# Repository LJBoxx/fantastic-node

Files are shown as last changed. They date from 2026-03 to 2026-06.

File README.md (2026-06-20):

# fantastic-node
A meshtastic node designed to be self sufficient (solar powered) and small/unnoticeable enough to be planted in urban spaces.

I think that mestastic is a great project aiming at making an offgrid network of devices allowing for communication but as part of how it operates, it is limited by the cost and ease of implementing these community ran nodes transmitting packets across a city for instance. 

In this repo, you will find a pcb meant to be affordable, with a 3d printable case and easily sourcable parts.

## Schematic and PCB!

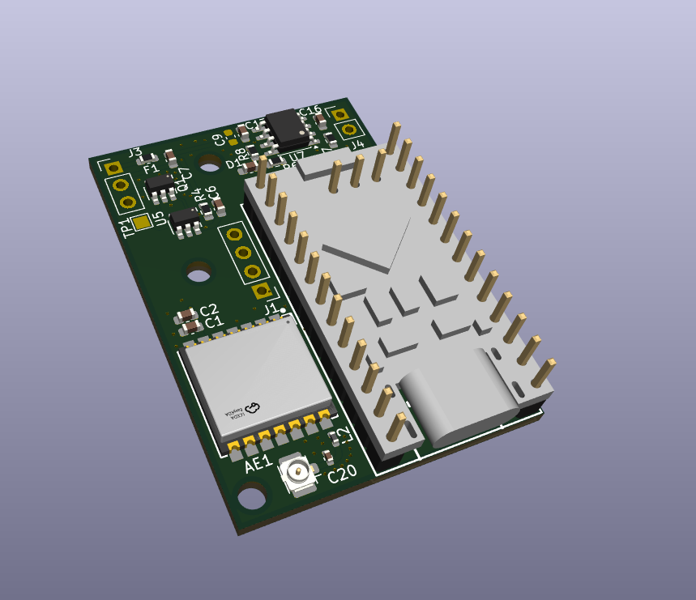
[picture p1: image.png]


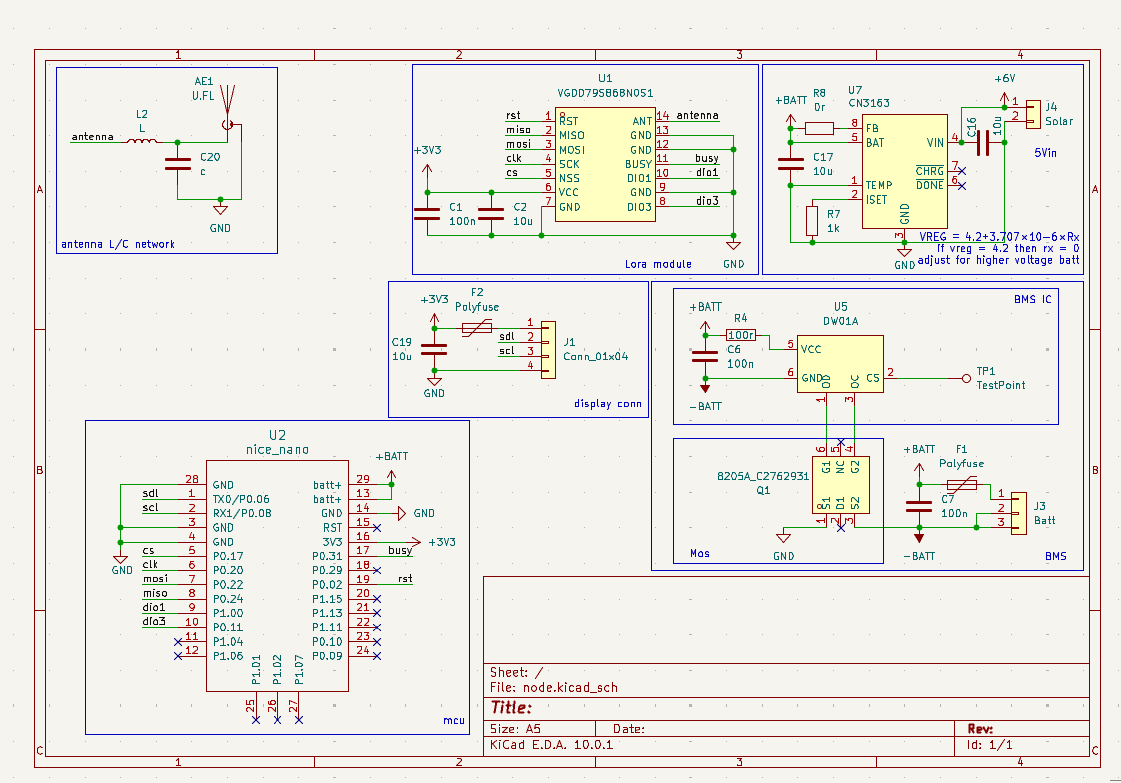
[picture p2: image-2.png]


## Full CAD assembly

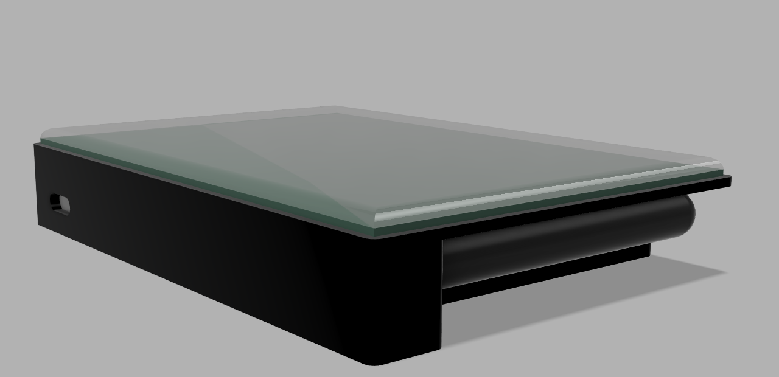
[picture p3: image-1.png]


# BOM 
| Name | Qty | Price  | Link | Note |
| --- | --- | --- | --- | ----- |
| Components | 1 | 20usd  | /hardware/bom_export_mesh.xls |
| PCB | 1x5pcs  | 5usd | https://jlcpcb.com/ | |
|3d printed parts | 2 | 0.1usd | N/A |  Print it yourself|
| total | | usd |  |shipping included

# Assembly

1. Assemble the pcb put all components together and soldere them using the schematic 
2. Print the case+parts and glue the solar pannel in place then place all heat inserts in holes
3. Build the firmware following [meshtastic instructions](https://meshtastic.org/docs/development/firmware/build/) using files in /firmware/* and flash with usb !
4. Put the board and wire antenna plug connect battery to terminals to test out if working and then glue the battery and screw everything together. Use the f3d file to help with assembly :3
(will add more details and pics once i make it)

# ZINEE 
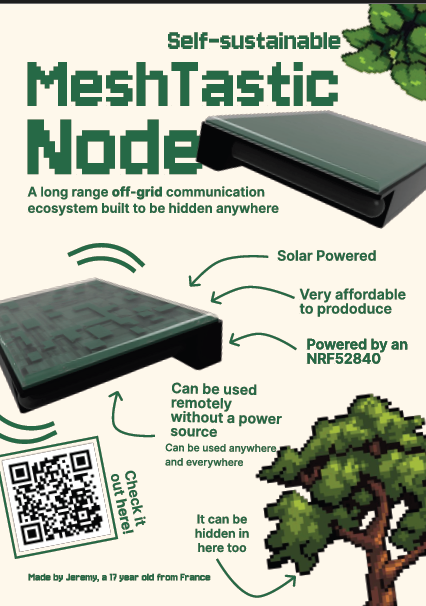
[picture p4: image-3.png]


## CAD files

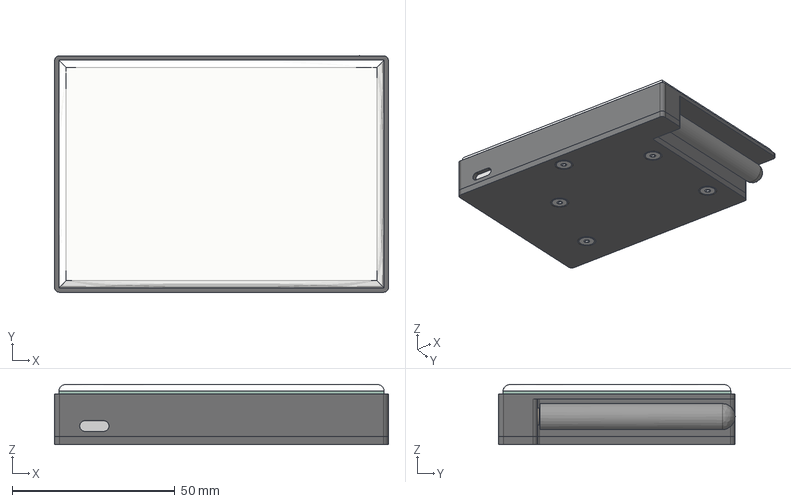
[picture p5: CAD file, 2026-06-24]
hardware/3d/assembly.step
102.7 x 72.7 x 18.5 mm
SOT-23-6 x 2
C_0603_1608Metric x 8
L_0402_1005Metric
SOIC-8_3.9x4.9mm_P1.27mm
R_0603_1608Metric x 4
promicronrf52840
PinHeader_1x13_P2.54mm_Vertical x 2
PinHeader_1x03_P2.54mm_Vertical
WIRELM-SMD_L11.5-W11.5-P1.50-BL
WIRELM-SMD_L11.5-W11.5-P1.50-BL_1
U.FL_Hirose_U.FL-R-SMT-1_Vertical
C_0402_1005Metric
Fuse_0603_1608Metric
node_silkscreen
node_silkscreen_1
node_soldermask
node_soldermask_1
node_PCB
solar module
case
RP-SMA FEMALE TO 90DEG MALE
antenna
battery
SOT-23-6_1 x 2
C_0603_1608Metric_1 x 8
L_0402_1005Metric_1
SOIC-8_3.9x4.9mm_P1.27mm_1
R_0603_1608Metric_1 x 4
promicronrf52840_1
PinHeader_1x13_P2.54mm_Vertical_1 x 2
PinHeader_1x03_P2.54mm_Vertical_1
WIRELM-SMD_L11.5-W11.5-P1.50-BL_2
WIRELM-SMD_L11.5-W11.5-P1.50-BL_3
U.FL_Hirose_U.FL-R-SMT-1_Vertical_1
C_0402_1005Metric_1
Fuse_0603_1608Metric_1
node_silkscreen_2
node_silkscreen_3
node_soldermask_2
node_soldermask_3
node_PCB_1
Insert_M3 x 5
rod
cover
91263A821_Zinc-Plated Alloy Steel Hex Drive Flat Head Screw_1 x 4
91263A863_Zinc-Plated Alloy Steel Hex Drive Flat Head Screw

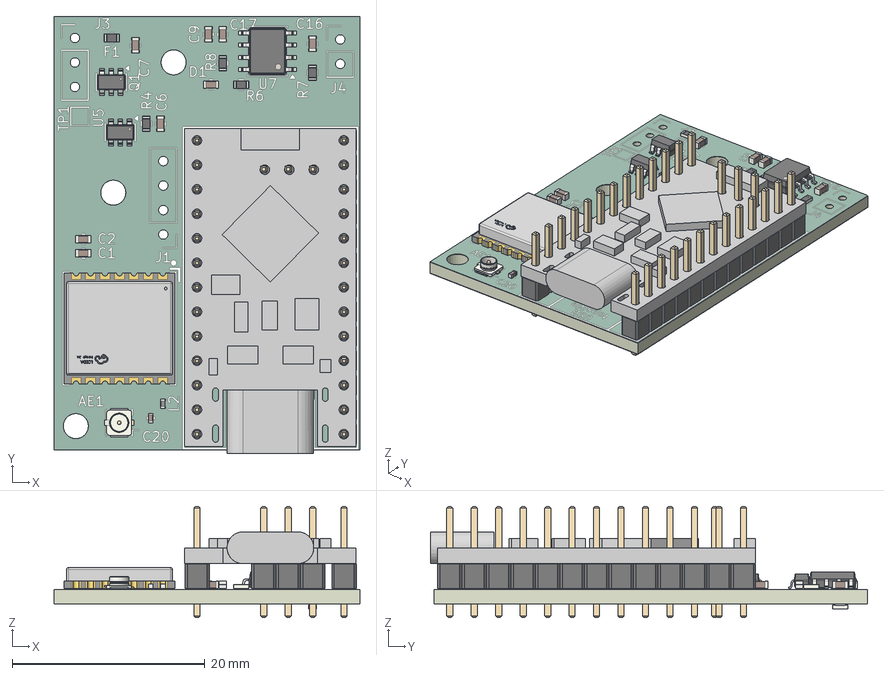
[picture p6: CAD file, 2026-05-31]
hardware/kicad/mesh_node_pcb.step
31.7 x 45.3 x 11.5 mm
SOT-23-6 x 2
C_0603_1608Metric x 8
L_0402_1005Metric
SOIC-8_3.9x4.9mm_P1.27mm
R_0603_1608Metric x 5
promicronrf52840
PinHeader_1x13_P2.54mm_Vertical x 2
PinHeader_1x03_P2.54mm_Vertical
WIRELM-SMD_L11.5-W11.5-P1.50-BL x 2
U.FL_Hirose_U.FL-R-SMT-1_Vertical
C_0402_1005Metric
Fuse_0603_1608Metric
node_silkscreen x 2
node_soldermask x 2
node_PCB

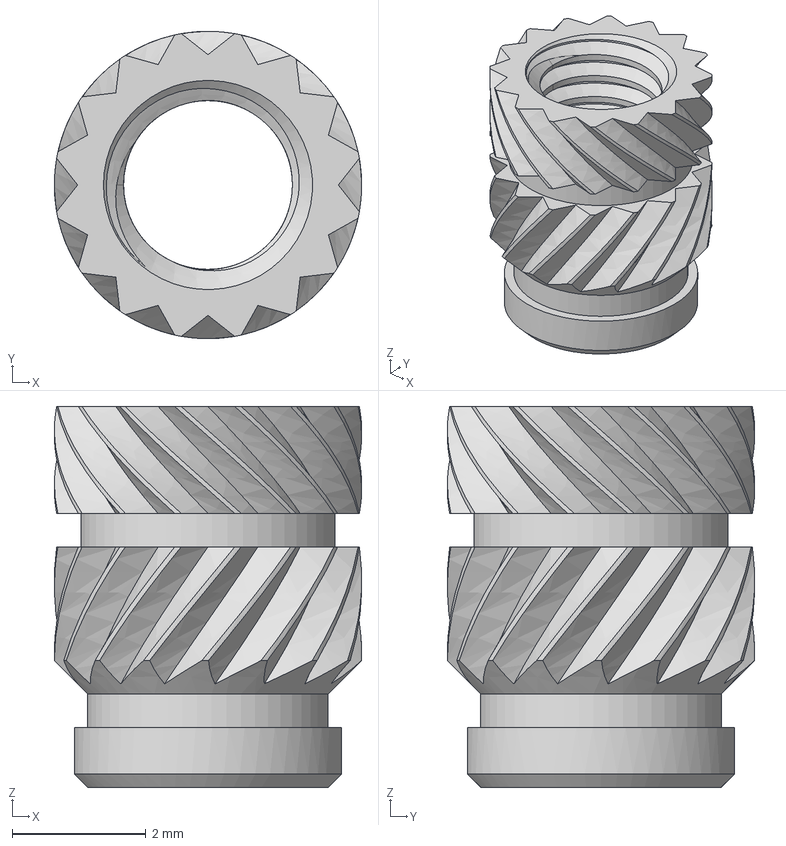
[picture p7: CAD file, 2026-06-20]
hardware/3d/M3_Standard.step
4.60 x 4.60 x 5.70 mm

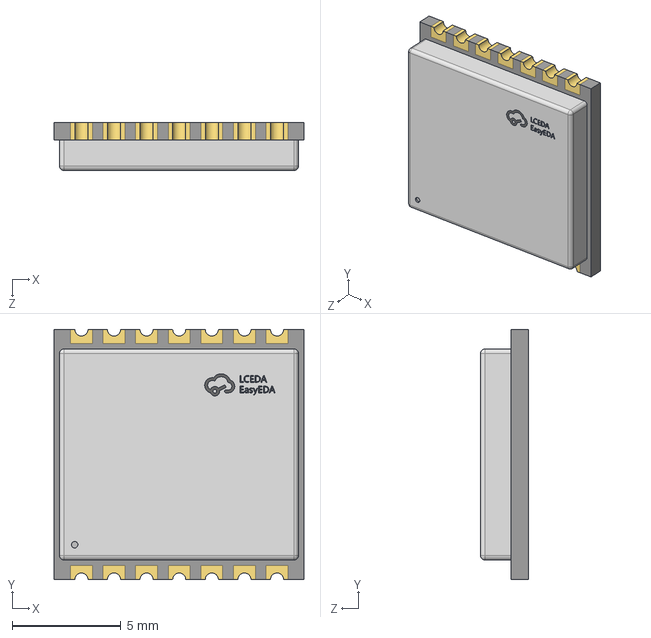
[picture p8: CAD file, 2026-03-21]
hardware/kicad/3d/WIRELM-SMD_L11.5-W11.5-P1.50-BL.step
11.5 x 11.5 x 2.20 mm

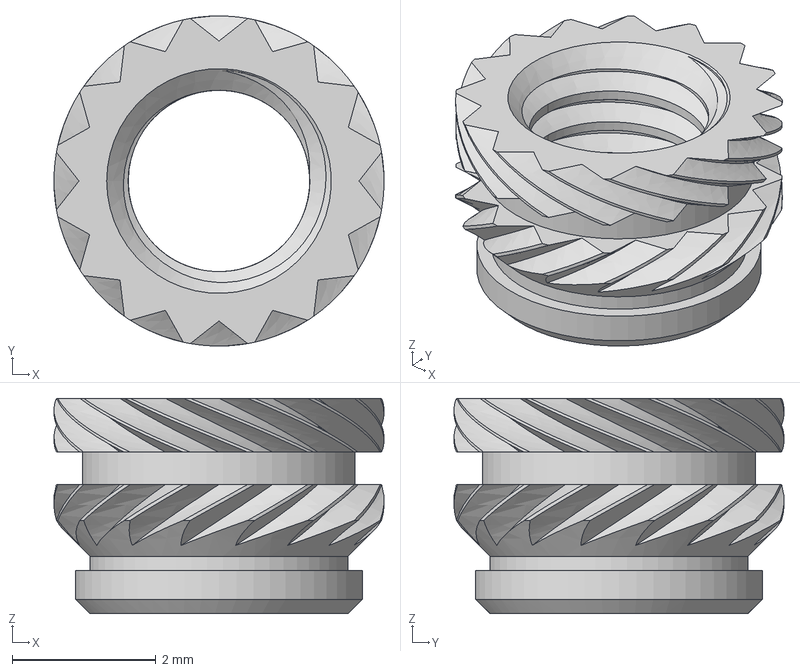
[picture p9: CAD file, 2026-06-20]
hardware/3d/M3_Short.step
4.60 x 4.60 x 3.00 mm

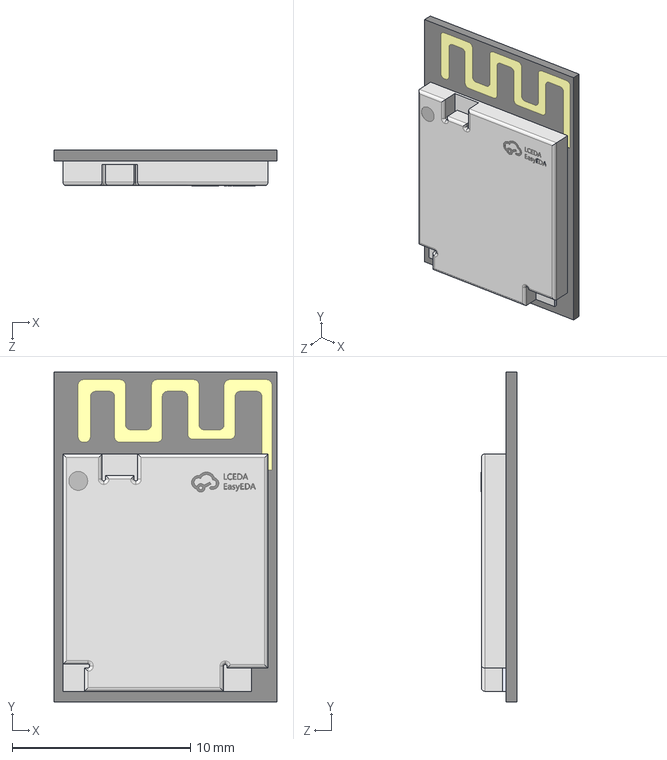
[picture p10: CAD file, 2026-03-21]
hardware/kicad/3d/BULETM-SMD_MS88SF3_V1.0.step
12.5 x 18.5 x 2.01 mm

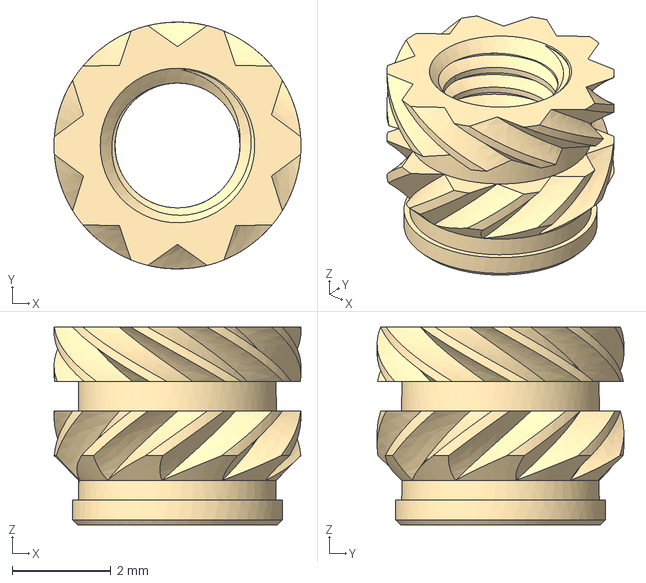
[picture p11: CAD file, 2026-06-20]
hardware/3d/M3_VORON.step
5.00 x 5.00 x 4.00 mm

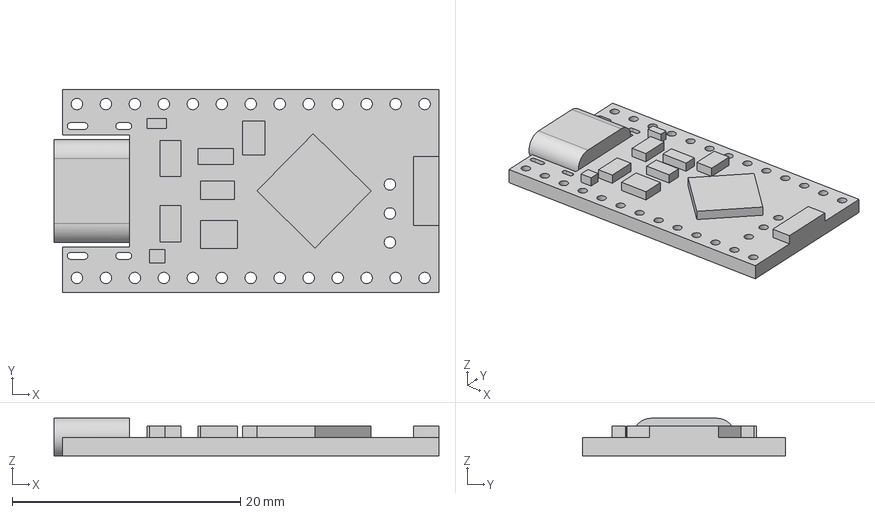
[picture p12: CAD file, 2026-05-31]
hardware/kicad/3d/nrf52840.step
33.7 x 17.8 x 3.30 mm

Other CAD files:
hardware/3d/node-v14.f3z

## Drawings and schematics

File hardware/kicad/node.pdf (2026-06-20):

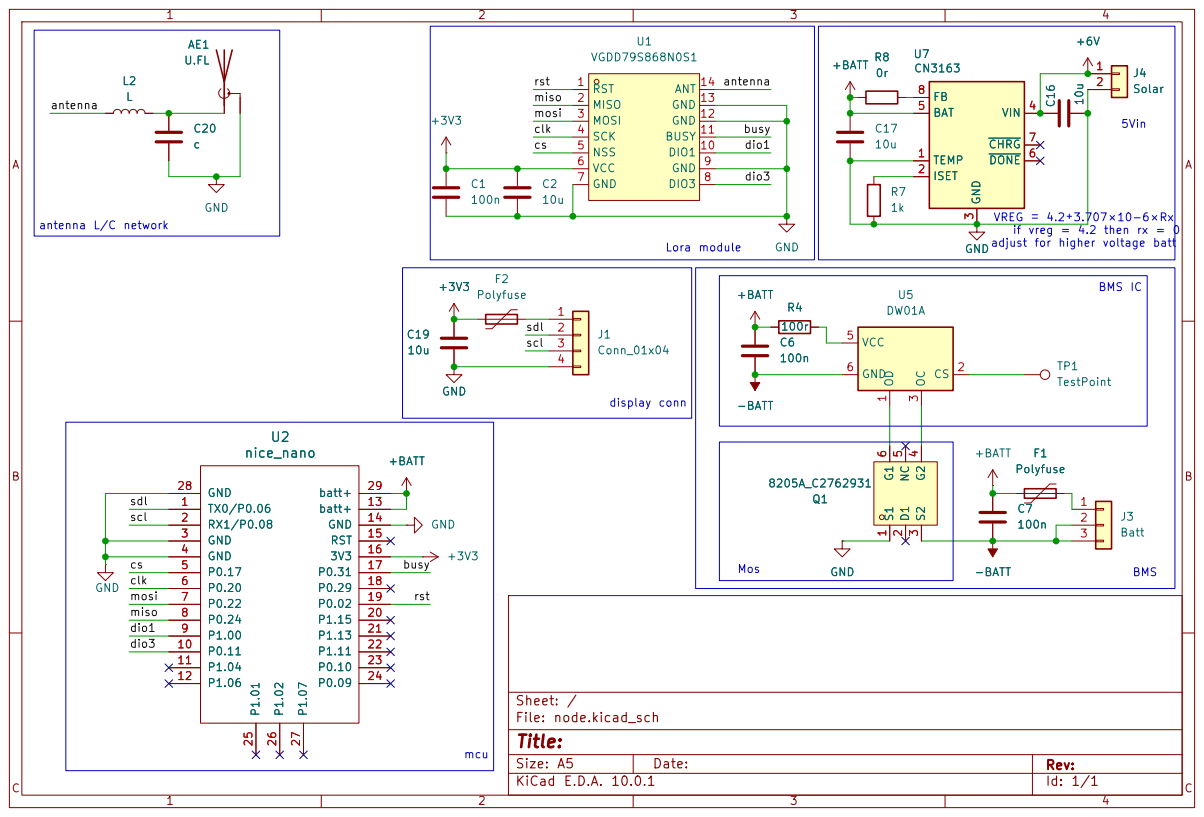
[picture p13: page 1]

if vreg = 4.2 then rx = 0
adjust for higher voltage batt BMS IC

Size: A5 | Rev: | C Date:
KiCad E.D.A. 10.0.1 | Id: 1/1

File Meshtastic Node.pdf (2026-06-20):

# MeshTastic

# Node

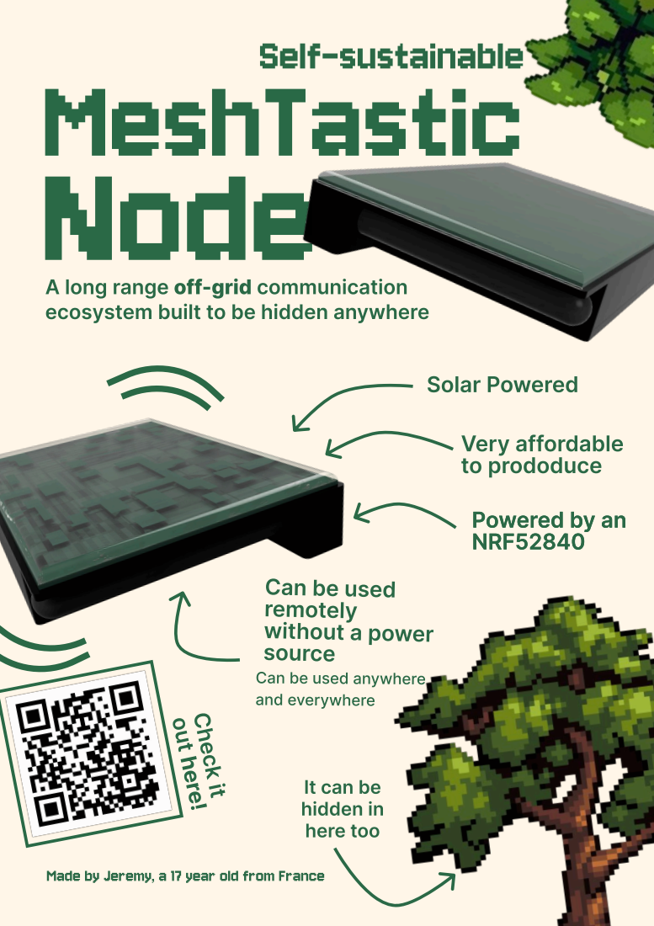
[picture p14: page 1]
Self-sustainable; Solar Powered; out here!; Check it; remotely without a power source

A long range off-grid communication
ecosystem built to be hidden anywhere

Very affordable to prododuce

Powered by an
NRF52840

Can be used

Can be used anywhere
and everywhere

It can be
hidden in
here too

Made by Jeremy, a 17 year old from France

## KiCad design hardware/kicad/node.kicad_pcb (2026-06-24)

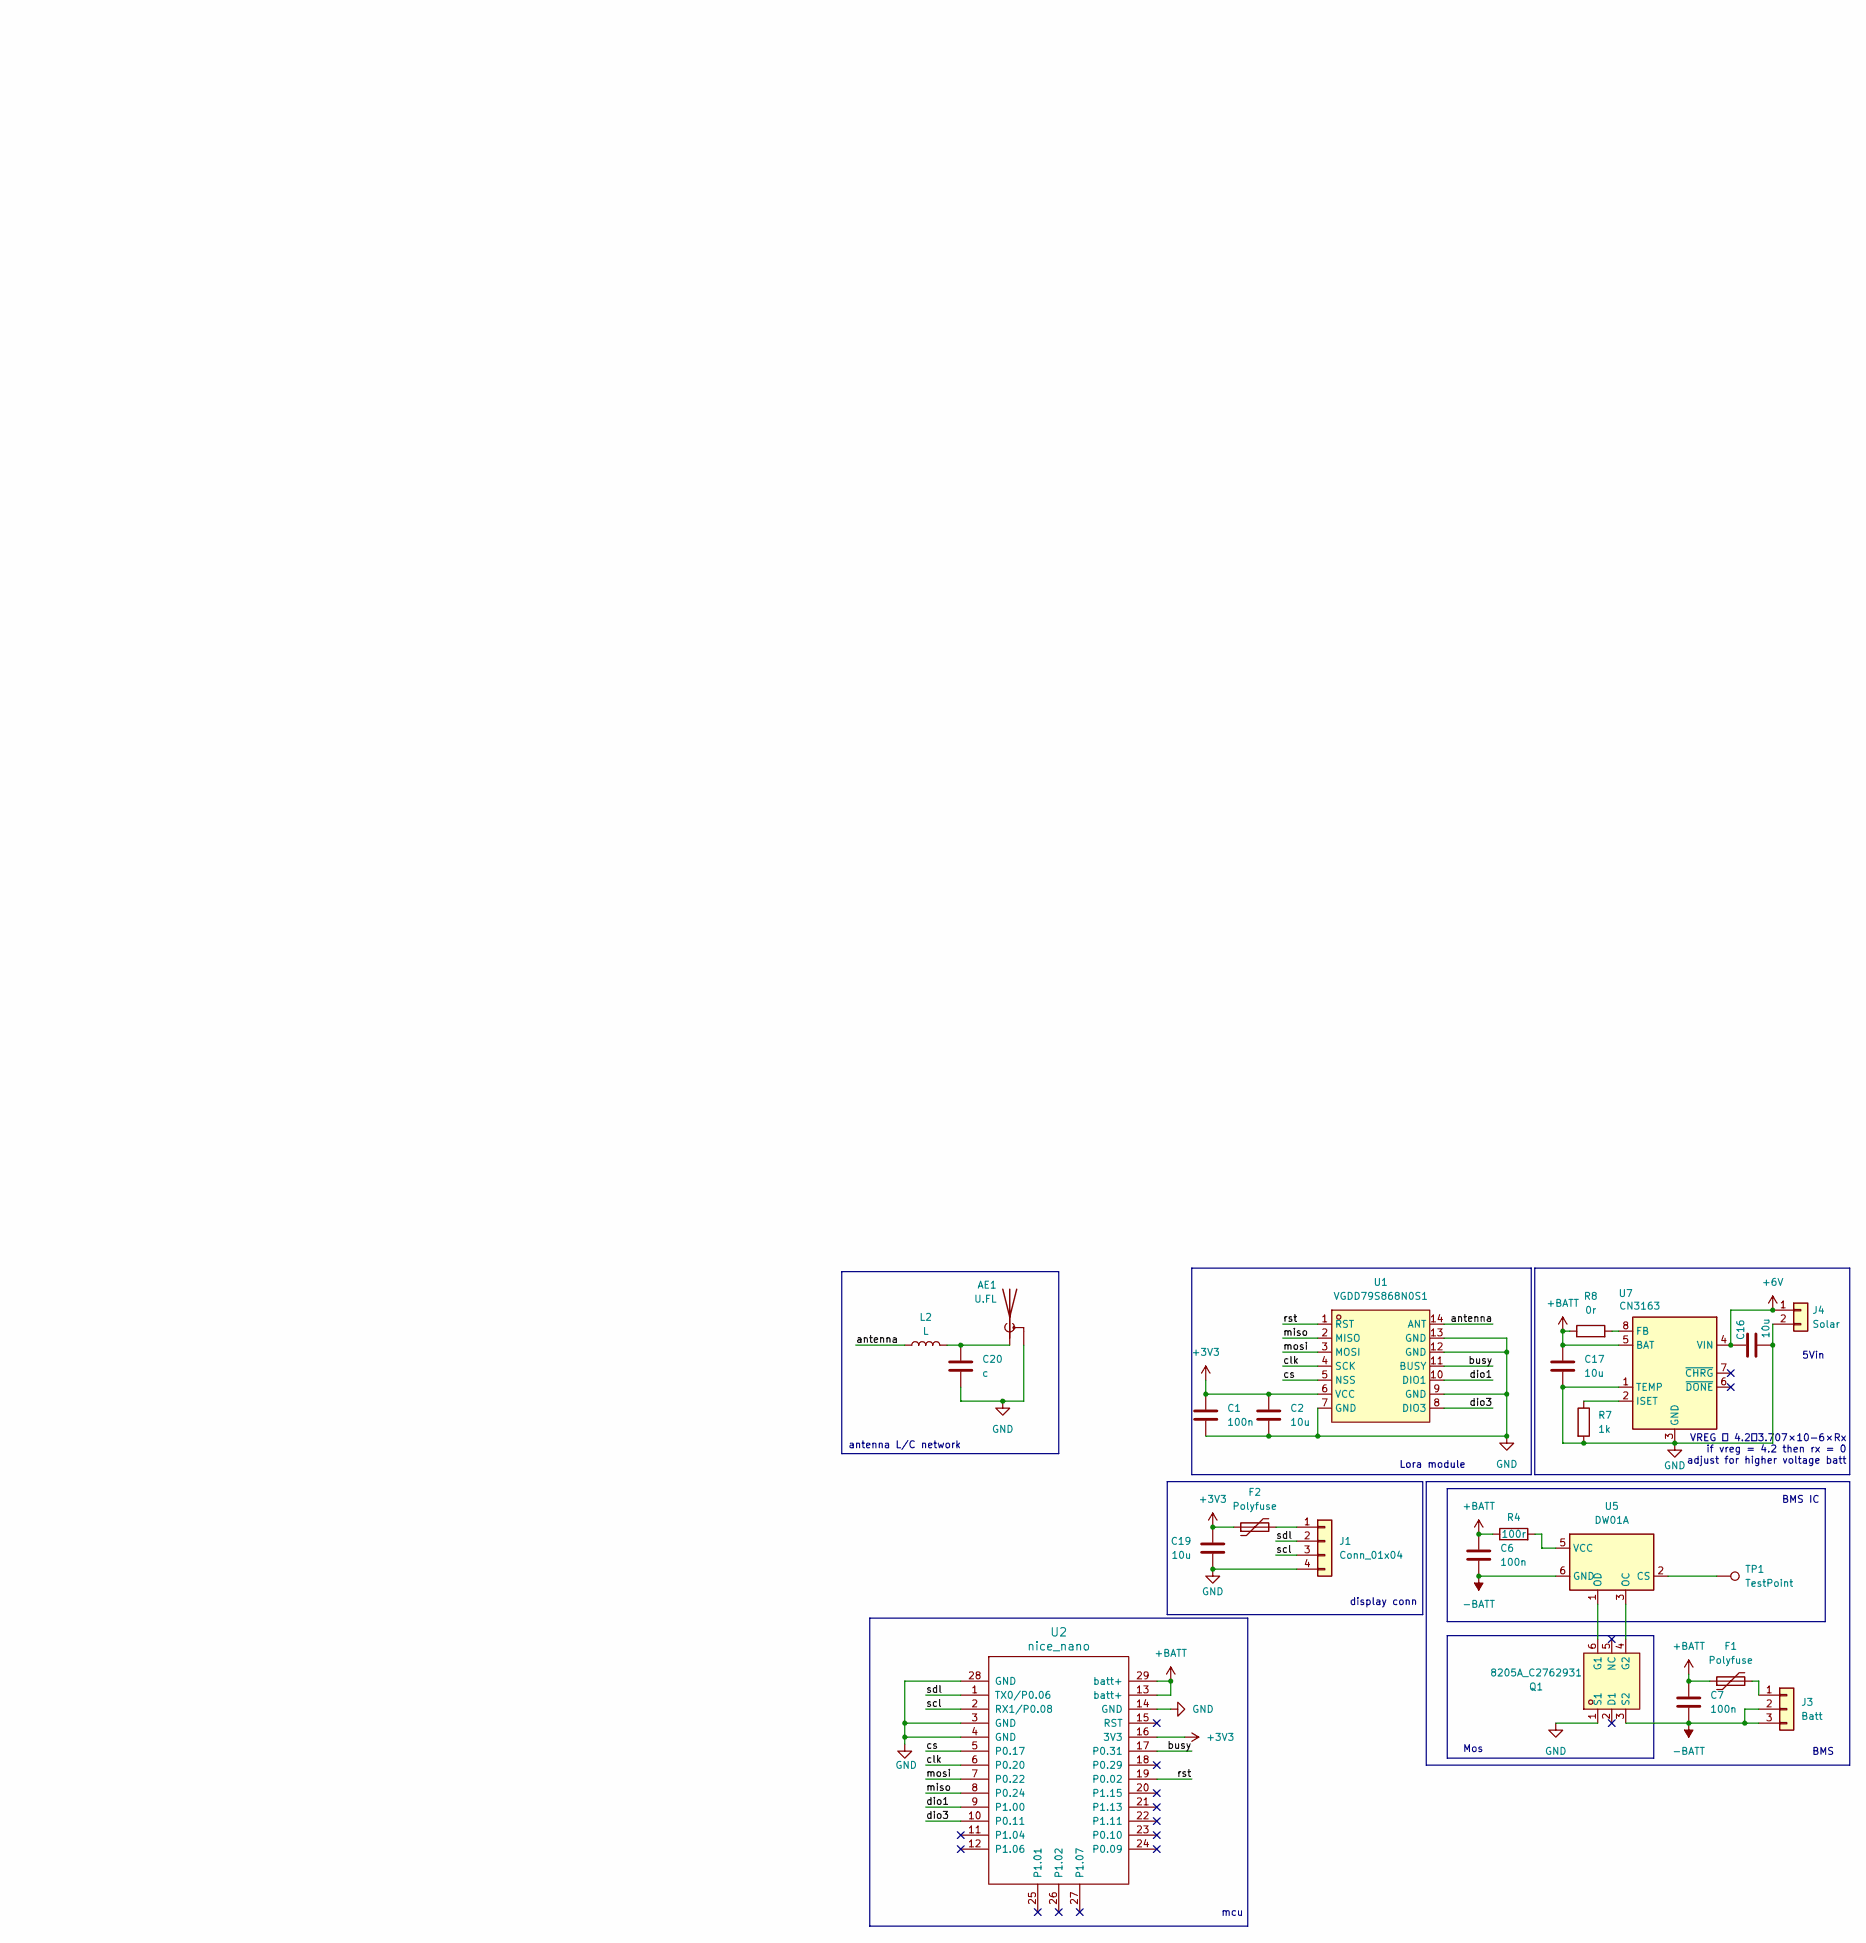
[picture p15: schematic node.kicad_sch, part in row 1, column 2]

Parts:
AE1: U.FL; U.FL_Hirose_U.FL-R-SMT-1_Vertical; LCSC Part C88374
C1, C6, C7: 100n; C_0603_1608Metric; LCSC Part C24497
C2, C16, C17, C19: 10u; C_0603_1608Metric; LCSC Part C962136
C20: c; C_0402_1005Metric; LCSC Part x
F1, F2: Polyfuse; Fuse_0603_1608Metric; LCSC Part C49318281
J1: Conn_01x04; PinHeader_1x04_P2.54mm_Vertical; LCSC Part x
J3: Batt; PinHeader_1x03_P2.54mm_Vertical; LCSC Part x
J4: Solar; PinHeader_1x02_P2.54mm_Vertical; LCSC Part x
L2: L; L_0402_1005Metric; LCSC Part C242160
Q1: 8205A_C2762931; SOT-23-6; LCSC Part C2762931
R4: 100r; R_0603_1608Metric; LCSC Part C105588
R7: 1k; R_0603_1608Metric; LCSC Part C7422246
R8: 0r; R_0603_1608Metric; LCSC Part x
TP1: TestPoint; TestPoint_Pad_1.5x1.5mm; LCSC Part x
U1: VGDD79S868N0S1; WIRELM-SMD_L11.5-W11.5-P1.50-BL; LCSC Part C2848400
U2: nice_nano; SuperMini NRF52840; LCSC Part x
U5: DW01A; SOT-23-6; LCSC Part C39846919
U7: CN3163; SOIC-8-1EP_3.9x4.9mm_P1.27mm_EP2.41x3.3mm_ThermalVias; LCSC Part C559031

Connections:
+3V3: C1.1, C2.1, C19.1, F2.1, U1.6 (VCC), U2.16 (3V3)
+6V: C16.1, J4.1, U7.4 (VIN)
+BATT: C6.1, C7.1, C17.1, F1.1, R4.1, R8.1, U2.13 (batt+), U2.29 (batt+), U7.5 (BAT)
-BATT: C6.2, C7.2, J3.2, J3.3, Q1.3 (S2), U5.6 (GND)
/antenna: L2.1, U1.14 (ANT)
/busy: U1.11 (BUSY), U2.17 (P0.31)
/chrg: U7.7 (~CHRG)
/clk: U1.4 (SCK), U2.6 (P0.20)
/cs: U1.5 (NSS), U2.5 (P0.17)
/dio1: U1.10 (DIO1), U2.9 (P1.00)
/dio3: U1.8 (DIO3), U2.10 (P0.11)
/miso: U1.2 (MISO), U2.8 (P0.24)
/mosi: U1.3 (MOSI), U2.7 (P0.22)
/rst: U1.1 (RST), U2.19 (P0.02)
/scl: J1.3, U2.2 (RX1/P0.08)
/sdl: J1.2, U2.1 (TX0/P0.06)
GND: AE1.2 (Shield), C1.2, C2.2, C16.2, C17.2, C19.2, C20.2, J1.4, J4.2, Q1.1 (S1), R7.2, U1.7 (GND), U1.9 (GND), U1.12 (GND), U1.13 (GND), U2.3 (GND), U2.4 (GND), U2.14 (GND), U2.28 (GND), U7.1 (TEMP), U7.3 (GND), U7.9 (GND)
unnamed: AE1.1 (A), C20.1, L2.2
unnamed: F2.2, J1.1
unnamed: F1.2, J3.1
unnamed: Q1.6 (G1), U5.1 (OD)
unnamed: Q1.4 (G2), U5.3 (OC)
unnamed: TP1.1 (1_1), U5.2 (CS)
unnamed: R4.2, U5.5 (VCC)
unnamed: R8.2, U7.8 (FB)
unnamed: R7.1, U7.2 (ISET)

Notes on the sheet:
BMS
mcu
VREG ＝ 4.2＋3.707×10-6×Rx if vreg = 4.2 then rx = 0 adjust for higher voltage batt
antenna L/C network
display conn
5Vin
BMS IC
Lora module
NRF52840
Mos

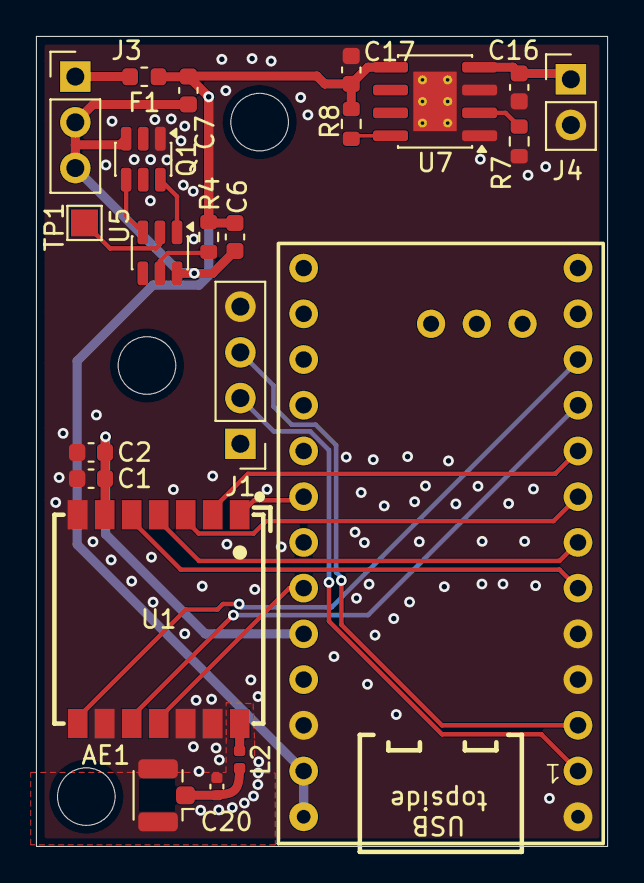
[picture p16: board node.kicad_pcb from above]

Board: 2 copper layers, 31.7 x 45.0 mm, 22 parts (0 on the bottom side), 24 nets.

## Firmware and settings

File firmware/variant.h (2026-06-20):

#ifndef _VARIANT_PROMICRO_DIY_
#define _VARIANT_PROMICRO_DIY_

/** Master clock frequency */
#define VARIANT_MCK (64000000ul)

// #define USE_LFXO // Board uses 32khz crystal for LF
#define USE_LFRC // Board uses RC for LF

#define PROMICRO_DIY_TCXO

/*----------------------------------------------------------------------------
 *        Headers
 *----------------------------------------------------------------------------*/

#include "WVariant.h"

#ifdef __cplusplus
extern "C" {
#endif // __cplusplus

/*
NRF52 PRO MICRO PIN ASSIGNMENT -- do not follow - not updated 

| Pin   | Function    |     | Pin      | Function     | RF95  |
| ----- | ----------- | --- | -------- | ------------ | ----- |
| Gnd   |             |     | vbat     |              |       |
| P0.06 | Serial2 RX  |     | vbat     |              |       |
| P0.08 | Serial2 TX  |     | Gnd      |              |       |
| Gnd   |             |     | reset    |              |       |
| Gnd   |             |     | ext_vcc  | *see 0.13    |       |
| P0.17 | RXEN        |     | P0.31    | BATTERY_PIN  |       |
| P0.20 | GPS_TX      |     | P0.29    | BUSY         | DIO0  |
| P0.22 | GPS_RX      |     | P0.02    | MISO         | MISO  |
| P0.24 | GPS_EN      |     | P1.15    | MOSI         | MOSI  |
| P1.00 | BUTTON_PIN  |     | P1.13    | CS           | CS    |
| P0.11 | SCL         |     | P1.11    | SCK          | SCK   |
| P1.04 | SDA         |     | P0.10    | DIO1/IRQ     | DIO1  |
| P1.06 | Free pin    |     | P0.09    | RESET        | RST   |
|       |             |     |          |              |       |
|       | Mid board   |     |          | Internal     |       |
| P1.01 | Free pin    |     | 0.15     | LED          |       |
| P1.02 | Free pin    |     | 0.13     | 3V3_EN       |       |
| P1.07 | Free pin    |     |          |              |       |
*/

// Number of pins defined in PinDescription array
#define PINS_COUNT (48)
#define NUM_DIGITAL_PINS (48)
#define NUM_ANALOG_INPUTS (1)
#define NUM_ANALOG_OUTPUTS (0)

// Pin 13 enables 3.3V periphery. If the Lora module is on this pin, then it should stay enabled at all times.
#define PIN_3V3_EN (0 + 13) // P0.13

// Analog pins
#define BATTERY_PIN (0 + 31) // P0.31 Battery ADC
#define ADC_CHANNEL ADC1_GPIO4_CHANNEL
#define ADC_RESOLUTION 14
#define BATTERY_SENSE_RESOLUTION_BITS 12
#define BATTERY_SENSE_RESOLUTION 4096.0
// Definition of milliVolt per LSB => 3.0V ADC range and 12-bit ADC resolution = 3000mV/4096
#define VBAT_MV_PER_LSB (0.73242188F)
// Voltage divider value => 1.5M + 1M voltage divider on VBAT = (1.5M / (1M + 1.5M))
#define VBAT_DIVIDER (0.6F)
// Compensation factor for the VBAT divider
#define VBAT_DIVIDER_COMP (1.73)
// Fixed calculation of milliVolt from compensation value
#define REAL_VBAT_MV_PER_LSB (VBAT_DIVIDER_COMP * VBAT_MV_PER_LSB)
#undef AREF_VOLTAGE
#define AREF_VOLTAGE 3.0
#define VBAT_AR_INTERNAL AR_INTERNAL_3_0
#define ADC_MULTIPLIER VBAT_DIVIDER_COMP // REAL_VBAT_MV_PER_LSB
#define VBAT_RAW_TO_SCALED(x) (REAL_VBAT_MV_PER_LSB * x)

// WIRE IC AND IIC PINS
#define WIRE_INTERFACES_COUNT 1

#define PIN_WIRE_SDA (32 + 4) // P1.04
#define PIN_WIRE_SCL (0 + 11) // P0.11

// LED
#define PIN_LED1 (0 + 15) // P0.15
// Actually red
#define LED_BLUE PIN_LED1
#define LED_STATE_ON 1 // State when LED is lit

// Button
//#define BUTTON_PIN (32 + 0) // P1.00

// GPS
//#define GPS_TX_PIN (0 + 20) // P0.20 - This is data from the MCU
//#define GPS_RX_PIN (0 + 22) // P0.22 - This is data from the GNSS

//#define PIN_GPS_EN (0 + 24) // P0.24
//#define GPS_UBLOX
// define GPS_DEBUG

// UART interfaces
//#define PIN_SERIAL1_TX GPS_TX_PIN
//#define PIN_SERIAL1_RX GPS_RX_PIN

//#define PIN_SERIAL2_RX (0 + 6) // P0.06
//#define PIN_SERIAL2_TX (0 + 8) // P0.08

// Serial interfaces
#define SPI_INTERFACES_COUNT 1

#define PIN_SPI_MISO (0 + 24)   // P0.24
#define PIN_SPI_MOSI (0 + 22) // P0.22
#define PIN_SPI_SCK (0 + 20)  // P0.20

#define LORA_MISO PIN_SPI_MISO
#define LORA_MOSI PIN_SPI_MOSI
#define LORA_SCK PIN_SPI_SCK
#define LORA_CS (0 + 17) // P0.17

// LORA MODULES
#define USE_LLCC68  //module used 
#define USE_SX1262
//#define USE_RF95
//#define USE_SX1268
//#define USE_LR1121

// RF95 CONFIG
/*
#define LORA_DIO0 (0 + 29) // P0.29 BUSY
#define LORA_DIO1 (0 + 10) // P0.10 IRQ
#define LORA_RESET (0 + 9) // P0.09 NRST
*/

// RX/TX for RFM95/SX127x
/*
#define RF95_RXEN (0 + 17)    // P0.17
#define RF95_TXEN RADIOLIB_NC // Assuming that DIO2 is connected to TXEN pin. If not, TXEN must be connected.
*/

// SX126X CONFIG
/
#define SX126X_CS (0 + 17)       // P0.17 FIXME - we really should define LORA_CS instead
#define SX126X_DIO1 (32 + 00)     // P1.00 IRQ
#define SX126X_DIO2_AS_RF_SWITCH // Note for E22 modules: DIO2 is not attached internally to TXEN for automatic TX/RX switching,
// so it needs connecting externally if it is used in this way
#define SX126X_BUSY (0 + 31)     // P0.31
#define SX126X_RESET (0 + 2)     // P0.02
#define SX126X_RXEN (0 + 11)     // P0.11
#define SX126X_TXEN RADIOLIB_NC  // Assuming that DIO2 is connected to TXEN pin. If not, TXEN must be connected.

// LR1121
/*
#ifdef USE_LR1121
#define LR1121_IRQ_PIN (0 + 10)      // P0.10 IRQ
#define LR1121_NRESET_PIN LORA_RESET // P0.09 NRST
#define LR1121_BUSY_PIN (0 + 29)     // P0.29 BUSY
#define LR1121_SPI_NSS_PIN LORA_CS   // P1.13
#define LR1121_SPI_SCK_PIN LORA_SCK
#define LR1121_SPI_MOSI_PIN LORA_MOSI
#define LR1121_SPI_MISO_PIN LORA_MISO
#define LR11X0_DIO3_TCXO_VOLTAGE 1.8
#define LR11X0_DIO_AS_RF_SWITCH
#endif
*/

// LR2021
/*
#define USE_LR2021
#define LR2021_IRQ_PIN (0 + 10)      // P0.10 IRQ
#define LR2021_NRESET_PIN LORA_RESET // P0.09 NRST
#define LR2021_BUSY_PIN (0 + 29)     // P0.29 BUSY
#define LR2021_SPI_NSS_PIN LORA_CS   // P1.13
#define LR2021_DIO3_TCXO_VOLTAGE 1.8
#define LR2021_DIO_AS_RF_SWITCH
#define LR2021_IRQ_DIO_NUM 9 // DIO9 → P0.10
*/

// #define SX126X_MAX_POWER 8 set this if using a high-power board!

/*
On the SX1262, DIO3 sets the voltage for an external TCXO, if one is present. If one is not present, use TCXO_OPTIONAL to try both
settings.
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

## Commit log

2026-03-21 first session, setup schematic almost finished
    next need to wire the lora module and double check everything
    [BULETM-SMD_MS88SF3_V1.0.step, WIRELM-SMD_L11.5-W11.5-P1.50-BL.step, node.kicad_pcb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]
2026-03-22 pcbbbb placement of parts etc
    [node.kicad_pcb, node.kicad_sch]
2026-03-24 added schematic
2026-04-21 ufl antenna
    [node.kicad_pcb, node.kicad_sch]
2026-05-25 push before fork
    [node-v14.f3z, node.kicad_pcb, node.kicad_sch]
2026-06-24 reorg + fixes
    [BULETM-SMD_MS88SF3_V1.0.step, Bill Of Materials.csv, M3_Short.step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]
